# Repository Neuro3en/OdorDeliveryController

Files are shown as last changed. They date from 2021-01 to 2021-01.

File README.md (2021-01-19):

# OdorDeliveryController
Arduino shield for odor valve controller

This repo contains the PCB eagle files and the CAM files.
The Arduino code running on the µC

The related research:
https://www.cell.com/cell-reports/pdf/S2211-1247%2820%2930120-0.pdf

Both codes have three program options, identified on the arduino by LED1 ON, LED2 ON, LED1 and 2 ON.
in the script _3odors the three programs indicate the usage of the three odor valves (thus the use of three odors)
in the script A_B_AB, the three programs indicate the usage of valve/odor A, of valve/odor B, and of simultaneous usage of valves/odors AB

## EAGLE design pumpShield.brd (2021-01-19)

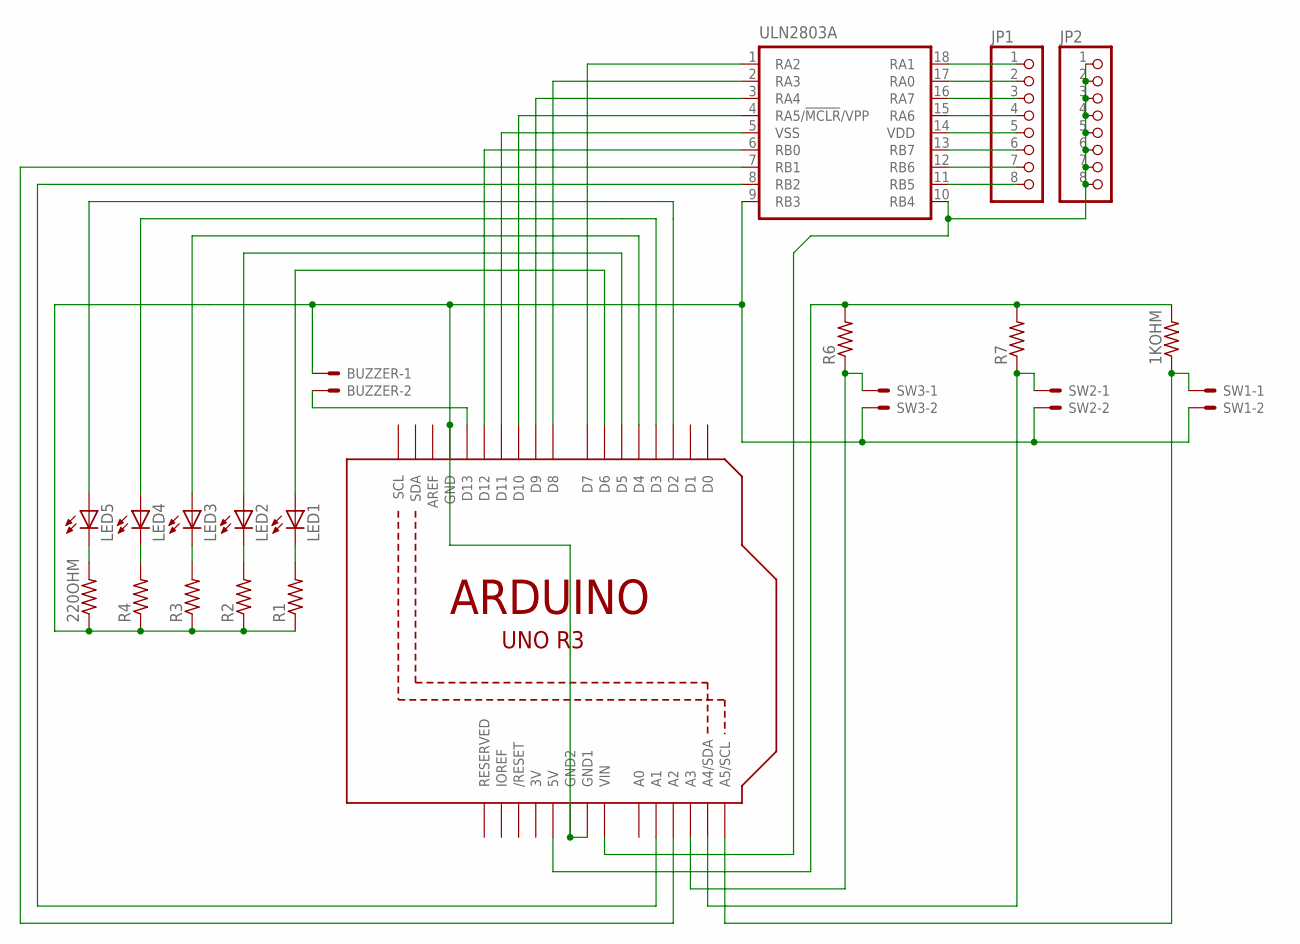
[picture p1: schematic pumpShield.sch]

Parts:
1KOHM, 220OHM: R-US_0207/9; 0207/9
BUZZER: 22-23-2021
JP1, JP2: PINHD-1X8CLEANBIG; 1X08-CLEANBIG
LED1, LED2, LED3, LED4, LED5: LED3MM
R1, R2, R3, R4, R6, R7: R-US_0207/9; 0207/9
SW1, SW2, SW3: 22-23-2021
U1: ARDUINOR3-DIMENSION; ARDUINOR3
ULN2803A: PIC16F1826/27P; DIL18

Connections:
3V: U1.3V
unnamed: 220OHM.1, BUZZER.1, R1.1, R2.1, R3.1, R4.1, SW1.2, SW2.2, SW3.2, U1.GND, U1.GND1, U1.GND2, ULN2803A.9 (RB3)
unnamed: JP2.1, JP2.2, JP2.3, JP2.4, JP2.5, JP2.6, JP2.7, JP2.8, U1.VIN, ULN2803A.10 (RB4)
unnamed: LED1.A, U1.D6
unnamed: LED2.A, U1.D5
unnamed: LED3.A, U1.D4
unnamed: LED4.A, U1.D3
unnamed: U1.D7, ULN2803A.1 (RA2)
unnamed: U1.D8, ULN2803A.2 (RA3)
unnamed: U1.D9, ULN2803A.3 (RA4)
unnamed: U1.D10, ULN2803A.4 (RA5/!MCLR!/VPP)
unnamed: U1.D11, ULN2803A.5 (VSS)
unnamed: U1.D12, ULN2803A.6 (RB0)
unnamed: LED1.K (C), R1.2
unnamed: LED2.K (C), R2.2
unnamed: LED3.K (C), R3.2
unnamed: LED4.K (C), R4.2
unnamed: 220OHM.2, LED5.K (C)
unnamed: LED5.A, U1.D2
unnamed: BUZZER.2, U1.D13
unnamed: 1KOHM.2, R6.2, R7.2, U1.5V
unnamed: JP1.8, ULN2803A.11 (RB5)
unnamed: JP1.7, ULN2803A.12 (RB6)
unnamed: JP1.6, ULN2803A.13 (RB7)
unnamed: JP1.5, ULN2803A.14 (VDD)
unnamed: JP1.4, ULN2803A.15 (RA6)
unnamed: JP1.3, ULN2803A.16 (RA7)
unnamed: R6.1, SW3.1, U1.A3
unnamed: R7.1, SW2.1, U1.A4 (A4/SDA)
unnamed: 1KOHM.1, SW1.1, U1.A5 (A5/SCL)
unnamed: U1.A1, ULN2803A.8 (RB2)
unnamed: U1.A2, ULN2803A.7 (RB1)
unnamed: JP1.2, ULN2803A.17 (RA0)
unnamed: JP1.1, ULN2803A.18 (RA1)

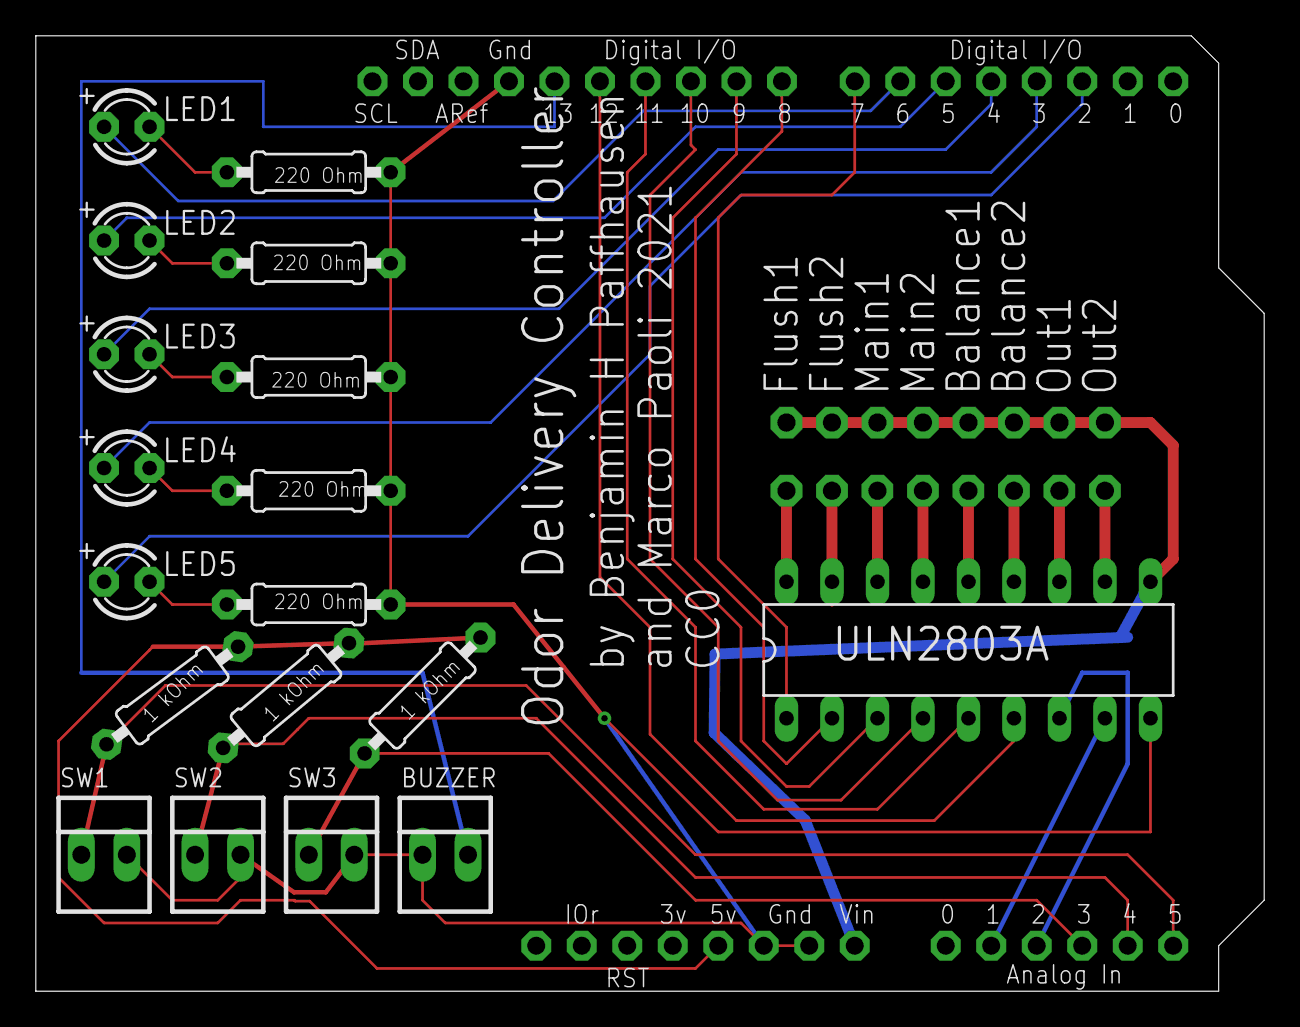
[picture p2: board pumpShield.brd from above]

Board: 2 copper layers, 68.6 x 53.3 mm, 21 parts (0 on the bottom side), 33 nets.

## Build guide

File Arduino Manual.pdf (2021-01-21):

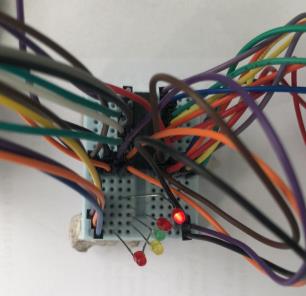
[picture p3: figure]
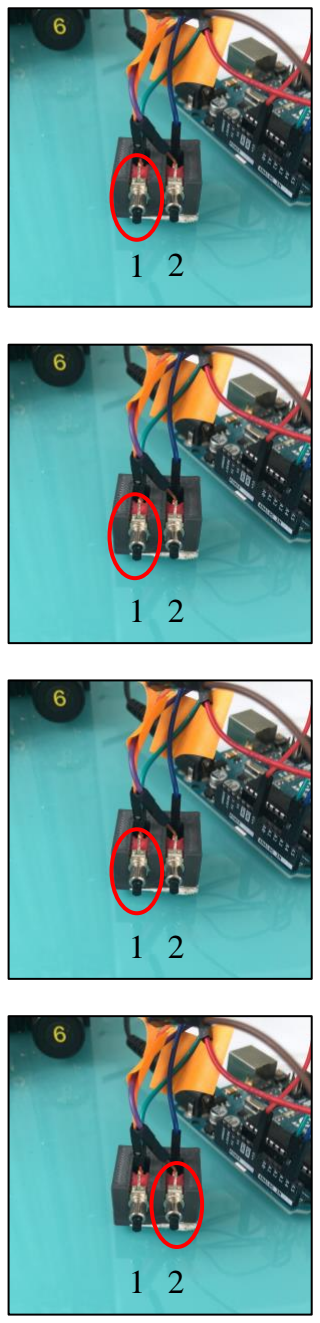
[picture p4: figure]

Selecting program 1:
Press once button 1 to select first program. First red LED is on.

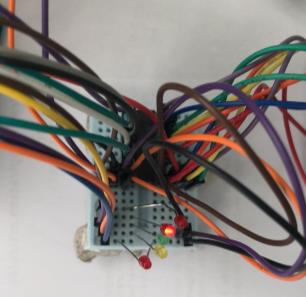
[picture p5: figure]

Selecting program 2:
Press once more button 1 to select second program.
Second red LED is on.

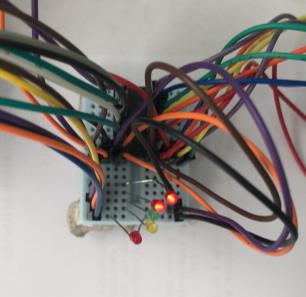
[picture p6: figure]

Selecting program 3:
Press once more button 1 to select third program.
Both first and second red LEDs are on.

Press button 1 again to go back to program 1.

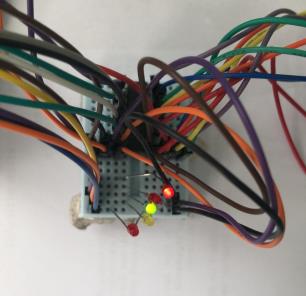
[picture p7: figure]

Running program:
Press once button 2 to start the previously selected program (program 1 here).

Familiarization phase: Green LED is on.

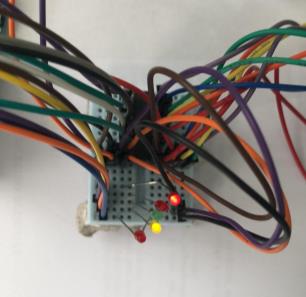
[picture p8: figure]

Running program:

CS stimulation: Yellow LED is on.

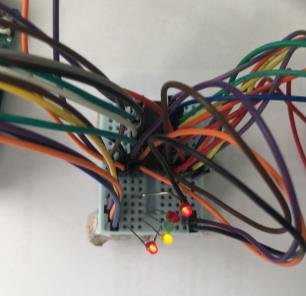
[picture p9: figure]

Running program:

US stimulation: Last red LED is on.
Note that CS and US are usually overlapping for some time (Cf. photo).

At the end of the program, last red LED is blinking. When it stops, another program can be selected to start again.

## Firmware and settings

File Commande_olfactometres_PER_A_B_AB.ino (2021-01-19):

int PushButton1 = 17; // define the 3 pins at which the pressbuttons will be connected
int PushButton2 = 18;
int PushButton3 = 19;
int LED1 = 6;
int LED2 = 5;
int LEDfam = 4;
int LEDcs = 3;
int LEDus = 2;
int Shock = 14;

int Familiarization = 25000; // define the time variables vith standard values
int CsAlone = 3000; 
int CsUs = 1000;
int UsAlone = 2000; 
int PostFamiliariazation = 25000; 
int ITIsur100 = 100;

int FlushValve1; // define the valves variables
int FlushValve2;
int MainValve1;
int MainValve2;
int BalanceValve1;
int BalanceValve2;
int Speaker = 13;
int X; // define the odor loading variable
int ProgramNumber = 1;

void setup() {
  // put your setup code here, to run once:
    pinMode(PushButton1, INPUT_PULLUP);
    pinMode(PushButton2, INPUT_PULLUP);
    pinMode(PushButton3, INPUT_PULLUP);
  for (int thisPin = 2; thisPin < 17; thisPin++) {
    pinMode(thisPin, OUTPUT); 
    // 2, 3, 4, 5, 6  // initiate LEDS
    // 7 and 8 and 15 are Flush Valves 
    // 9 and 10 and 16 are Main Valves
    // 11 is the Balance Valve
    // 13 is the speaker
    // 14 is the shock
  }
}

void loop() {
  // put your main code here, to run repeatedly:
  int ButtonState1 = digitalRead(PushButton1);
  int ButtonState2 = digitalRead(PushButton2);
  int ButtonState3 = digitalRead(PushButton3);

  // if the button 1 is pressed, use the first programmed parameters
  if (ButtonState1 == LOW) {
    if (ProgramNumber == 1) {
      ProgramNumber = 2;
      tone(Speaker, 587.33, 20);      // Speaker plays a tone of an D5 for 20ms
      Familiarization = 15000; // in milliseconds !!!!
      CsAlone = 3000; 
      CsUs = 1000;
      UsAlone = 1000; 
      PostFamiliariazation = 32000; 
      FlushValve1 = 7;
      FlushValve2 = 0;
      MainValve1 = 9;
      MainValve2 = 0;
      BalanceValve1 = 11;
      BalanceValve2 = 0;
      ITIsur100 = 50; 
      digitalWrite(LED1, HIGH); // Switch ON the program 1 LED
      digitalWrite(LED2, LOW);  // Switch OFF the program 2 LED
     }
      
    else if (ProgramNumber == 2) {
      ProgramNumber = 3;
      tone(Speaker, 587.33, 20);      // Speaker plays a tone of an D5 for 20ms
      Familiarization = 15000; // in milliseconds !!!!
      CsAlone = 3000; 
      CsUs = 1000;
      UsAlone = 1000; 
      PostFamiliariazation = 32000; 
      FlushValve1 = 8;
      FlushValve2 = 0;
      MainValve1 = 10;
      MainValve2 = 0;
      BalanceValve1 = 12;
      BalanceValve2 = 0;
      ITIsur100 = 50; 
      digitalWrite(LED1, LOW); // Switch OFF the program 1 LED
      digitalWrite(LED2, HIGH);  // Switch ON the program 2 LED
    }

    else if (ProgramNumber == 3) {
      ProgramNumber = 1;
      tone(Speaker, 587.33, 20);      // Speaker plays a tone of an D5 for 20ms
      Familiarization = 15000; // in milliseconds !!!!
      CsAlone = 3000; 
      CsUs = 1000;
      UsAlone = 1000; 
      PostFamiliariazation = 32000; 
      FlushValve1 = 7;
      FlushValve2 = 8;
      MainValve1 = 9;
      MainValve2 = 10;
      BalanceValve1 = 11;
      BalanceValve2 = 12;
      ITIsur100 = 50; 
      digitalWrite(LED1, HIGH); // Switch ON the program 1 LED
      digitalWrite(LED2, HIGH);  // Switch ON the program 2 LED
    }
    delay(500);
  }

  // if button 2 is pressed, start the active sequence
  if (ButtonState2 == LOW) {
//    while(1 == 1) {
      X = Familiarization - 5000;     // The odor must be uploaded during 5s before launching
      digitalWrite(LEDfam, HIGH);         // Switch ON the Familiarization LED
      delay(X);
      digitalWrite(FlushValve1, HIGH); // Switch the Flush Valve to NC (charge the cannon with the odor)
      digitalWrite(FlushValve2, HIGH);
      delay(5000);                    // during 5s
      
      tone(Speaker, 659.25, 20);           // Speaker plays a tone of an E5 for 20ms
      digitalWrite(BalanceValve1, HIGH);    // switch the balance valve to NC
      digitalWrite(BalanceValve2, HIGH);
      digitalWrite(MainValve1, HIGH);  // switch the Main valve to NC
      digitalWrite(MainValve2, HIGH);
      digitalWrite(LEDfam, LOW);      // Switch OFF the Familiarization LED
      digitalWrite(LEDcs, HIGH);      // Switch ON the Cs LED
      delay(CsAlone);
      
      tone(Speaker, 698.46, 20);      // Speaker plays a tone of an F5 for 20ms
      digitalWrite(LEDus, HIGH);      // Switch ON the Us LED
      digitalWrite(Shock, HIGH);      // Trigger shock 
      delay(CsUs);

      tone(Speaker, 783.99, 20);        // Speaker plays a tone of an G5 for 20ms
      digitalWrite(Shock, LOW);         // Stop trigger Shock (even if its pulsed)
      digitalWrite(FlushValve1, LOW);    // switch the flush valve to NO
      digitalWrite(FlushValve2, LOW);
      digitalWrite(BalanceValve1, LOW);  // switch the balance valve to NO 
      digitalWrite(BalanceValve2, LOW);
      digitalWrite(MainValve1, LOW);     // switch the Main valve to NO
      digitalWrite(MainValve2, LOW);
      digitalWrite(LEDcs, LOW);         // Switch OFF the Cs LED
      delay(UsAlone);

      tone(Speaker, 880, 20);          // Speaker plays a tone of an A5
      digitalWrite(LEDus, LOW);           // Switch OFF the Us LED
      delay(PostFamiliariazation);

      int k = 1;
      tone(Speaker, 880, 20);          // Speaker plays a tone of an A5
      while (k < 51){
        digitalWrite(LEDus, HIGH);         // Switch OFF the Cs LED
        delay(ITIsur100);                   // Wait for the ITI
        digitalWrite(LEDus, LOW);
        delay(ITIsur100);
        k=k+1;
      }
      tone(Speaker, 880, 20);          // Speaker plays a tone of an A5
//    }
  }
  delay(1); // delay for stability

  // if the button 3 is pressed, use the second programmed parameters
  if (ButtonState3 == LOW) {
    tone(Speaker, 987.77, 20);      // Speaker plays a tone of an B5 for 20ms
    
  }
}

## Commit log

2021-01-19 Add files via upload
    Eagle files of PCB and .RAR file including the CAM files for upload to PCB manufacturer
    [pumpShield.brd, pumpShield.sch]
2021-01-21 Add files via upload
    Arduino Manual describing the LEDs and Buttons

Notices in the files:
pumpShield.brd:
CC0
